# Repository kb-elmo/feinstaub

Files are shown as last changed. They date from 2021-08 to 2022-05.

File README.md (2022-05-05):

# Feinstaub

[][cc-by-sa]

## This project is completed and will not get updated anymore.

### ESP-12F powered piggyback PCB for the SDS011 fine dust sensor

The board is designed to run with the luftdaten.info firmware and has a place for a BME280 sensor.

Pic of the prototype (with enamel wire because it wouldn't be a prototype without it).
prototype

---

### BOM
 |Count|Part|Reference|Part URL|
 |-|-|-|-|
 |1|ESP12-F|U1|[ESP-12F](https://www.ebay.de/itm/255303527301)
 |1|Bosch BME-280 module|U2|[BME280](https://www.ebay.de/itm/255421634848)
 |1|Nova Fitness SDS-011 Module|---|[SDS-011](https://www.ebay.de/itm/255283289438)
 |1|AMS1117-3.3v step-down module|U3|[AMS1117-3.3 module](https://www.ebay.de/itm/174076431478)
 |1|DIP switch|SW1|[DIP-Switch](https://www.ebay.de/itm/255421634848)
 |1|100 nF ceramic disk capacitor|C1|[Kemet C315C104M5U5TA](https://octopart.com/c315c104m5u5ta-kemet-83288)
 |4|10 kΩ resistor|R1-R4|[Multicomp MF25 10k](https://octopart.com/mf25+10k-multicomp-2697429)

#### Assembly notes
The SDS011 module gets connected to the J2 pins on the main PCB.  
Remember that TX and RX have to be connected in reverse on the module.

The ESP chip can be flashed by connecting an ISP flasher to the J1 pins.  
To put the chip into flashing mode set the boot switch to on, plug in the power and then turn the switch back off.  
The easiest method of flashing the chip is by using the [AirRohr firmware updater](https://github.com/opendata-stuttgart/airrohr-firmware-flasher)

For the main power input a 5v / 0.5-1A power supply should be used.

DO NOT CONNECT BOTH THE MAIN POWER AND A USB FLASHER WITH POWER INPUT AT ONCE!!!  
If you use a flashing device that has 3.3v power output on it's own the main power has to be left unconnected.

---

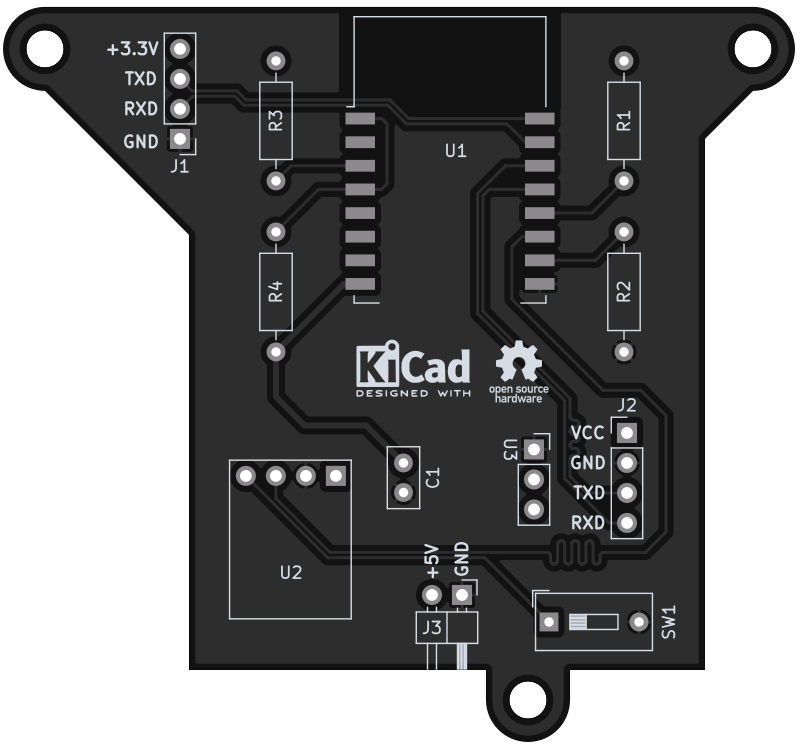
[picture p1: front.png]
render_front
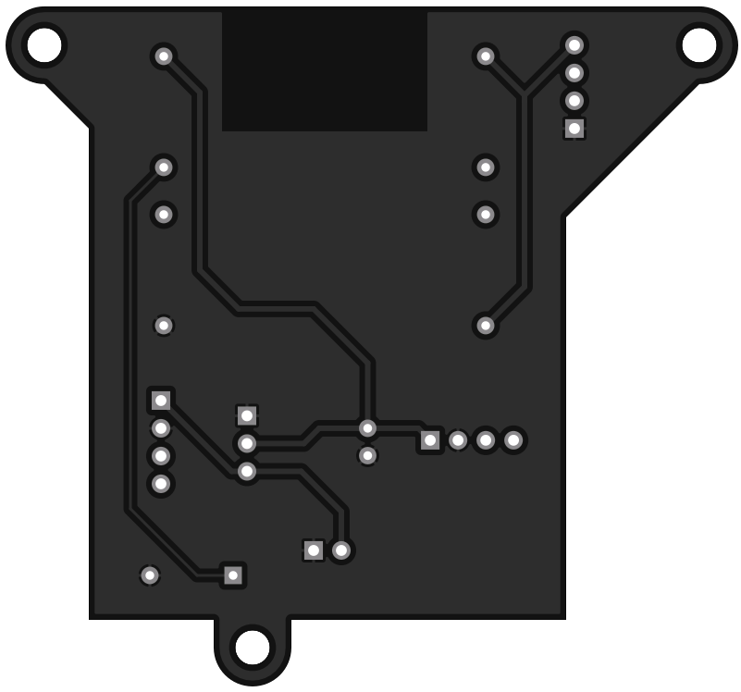
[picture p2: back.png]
render_back


---

This work is licensed under a
[Creative Commons Attribution-ShareAlike 4.0 International License][cc-by-sa].

[][cc-by-sa]

[cc-by-sa]: http://creativecommons.org/licenses/by-sa/4.0/
[cc-by-sa-image]: https://licensebuttons.net/l/by-sa/4.0/88x31.png
[cc-by-sa-shield]: https://img.shields.io/badge/License-CC%20BY--SA%204.0-lightgrey.svg

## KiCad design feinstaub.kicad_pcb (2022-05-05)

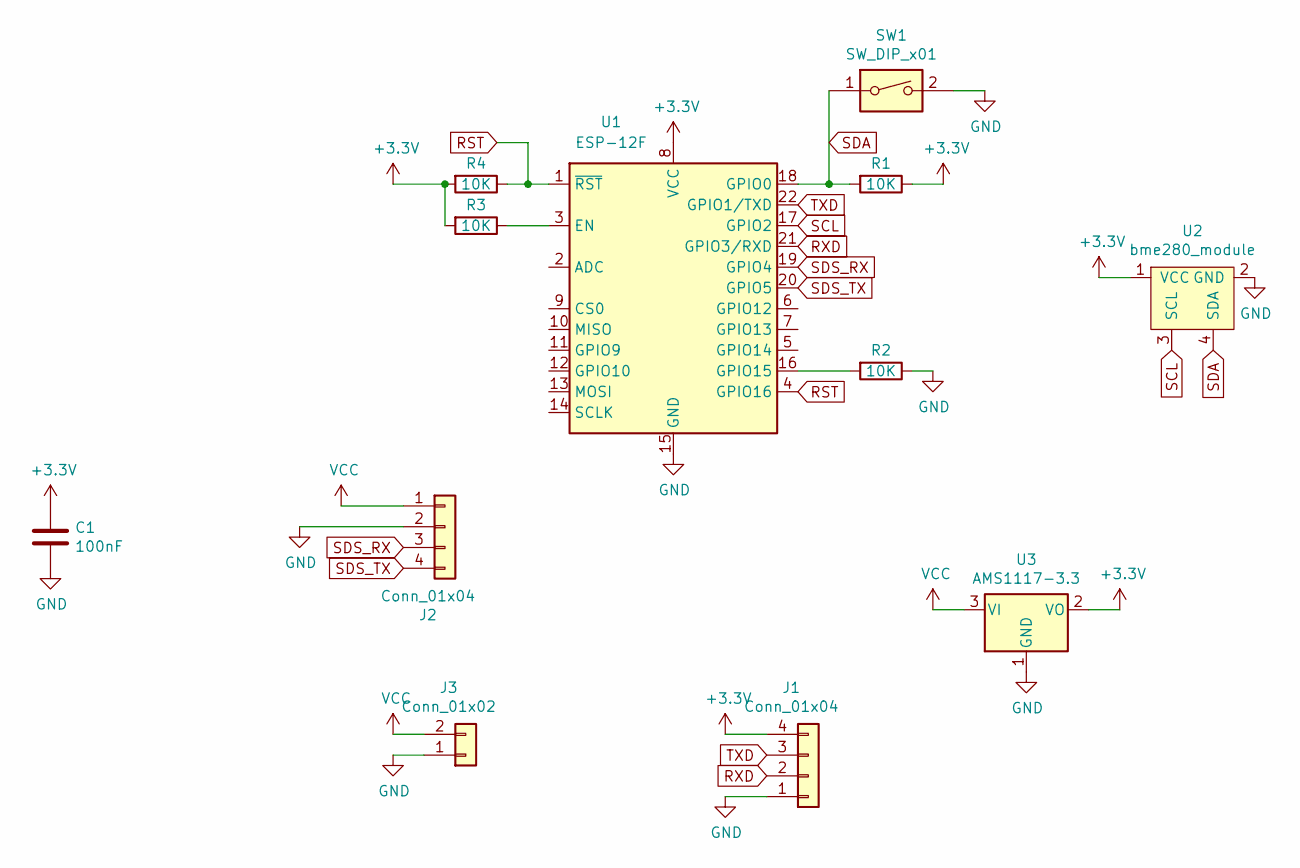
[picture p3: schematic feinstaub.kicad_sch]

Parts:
C1: 100nF; C_Disc_D5.0mm_W2.5mm_P2.50mm
J1, J2: Conn_01x04; PinHeader_1x04_P2.54mm_Vertical
J3: Conn_01x02; PinHeader_1x02_P2.54mm_Horizontal
R1, R2, R3, R4: 10K; R_Axial_DIN0207_L6.3mm_D2.5mm_P10.16mm_Horizontal
SW1: SW_DIP_x01; SW_DIP_SPSTx01_Slide_9.78x4.72mm_W7.62mm_P2.54mm
U1: ESP-12F
U2: bme280_module; bme280
U3: AMS1117-3.3; PinSocket_1x03_P2.54mm_Vertical

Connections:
+3V3: C1.1, J1.4, R1.1, R3.2, R4.2, U1.8 (VCC), U2.1 (VCC), U3.2 (VO)
GND: C1.2, J1.1, J2.2, J3.1, R2.1, SW1.2, U1.15 (GND), U2.2 (GND), U3.1 (GND)
unnamed: R2.2, U1.16 (GPIO15)
unnamed: R3.1, U1.3 (EN)
RST: R4.1, U1.1 (~RST), U1.4 (GPIO16)
RXD: J1.2, U1.21 (GPIO3/RXD)
SCL: U1.17 (GPIO2), U2.3 (SCL)
SDA: R1.2, SW1.1, U1.18 (GPIO0), U2.4 (SDA)
SDS_RX: J2.3, U1.19 (GPIO4)
SDS_TX: J2.4, U1.20 (GPIO5)
TXD: J1.3, U1.22 (GPIO1/TXD)
VCC: J2.1, J3.2, U3.3 (VI)

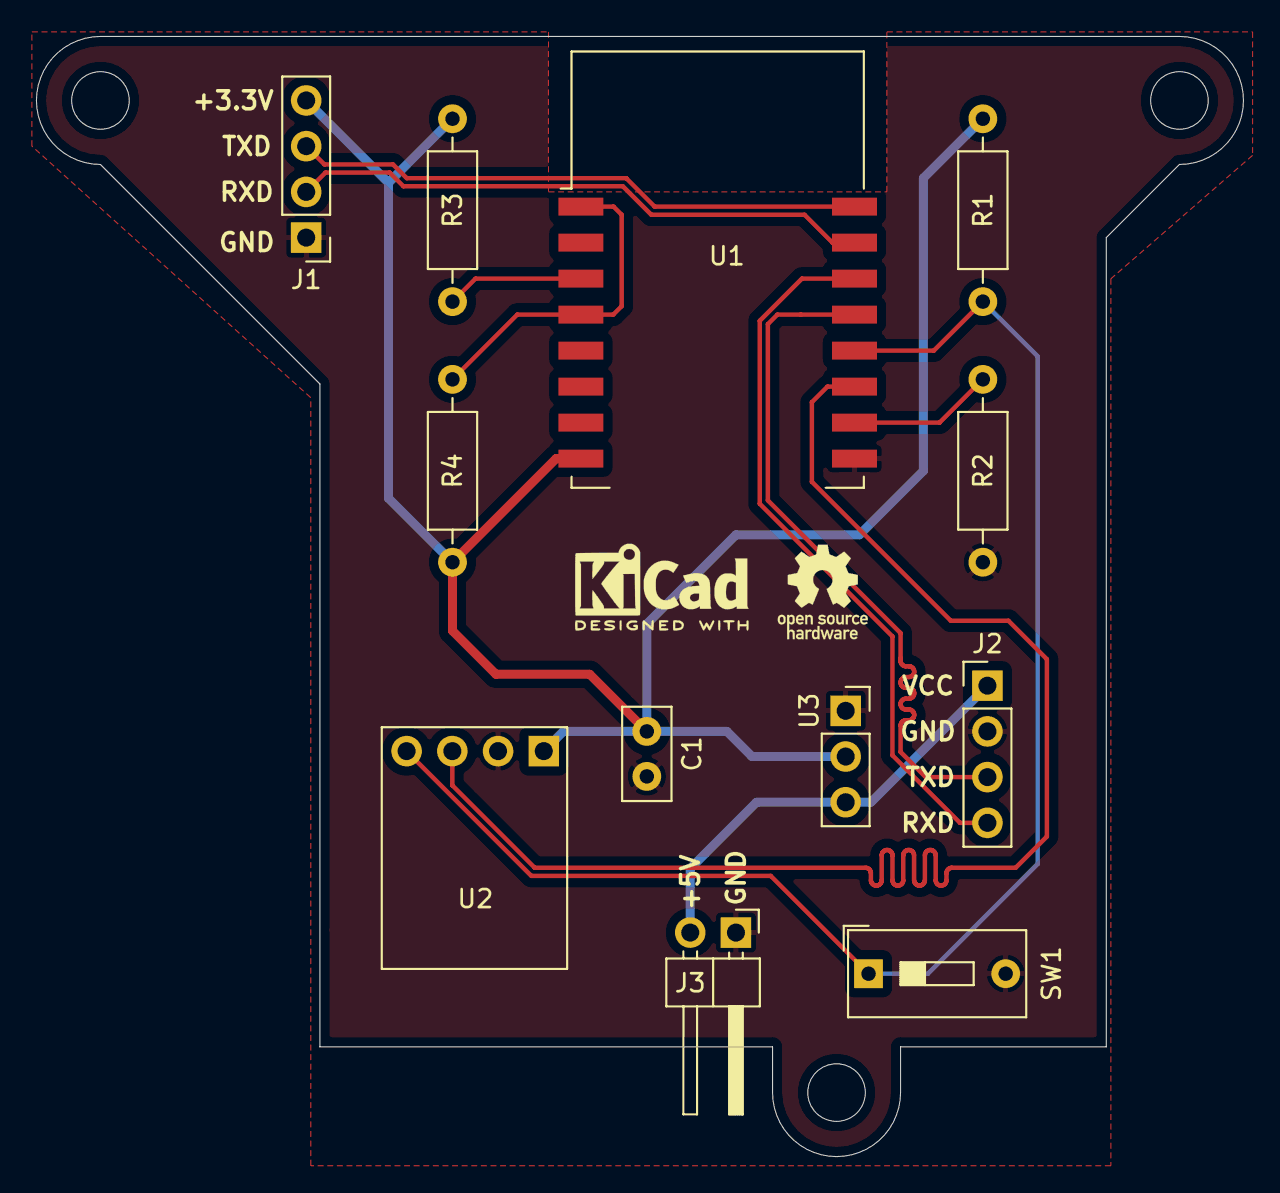
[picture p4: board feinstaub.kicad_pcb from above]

Board: 2 copper layers, 67.1 x 62.2 mm, 12 parts (0 on the bottom side), 12 nets.

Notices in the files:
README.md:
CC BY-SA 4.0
